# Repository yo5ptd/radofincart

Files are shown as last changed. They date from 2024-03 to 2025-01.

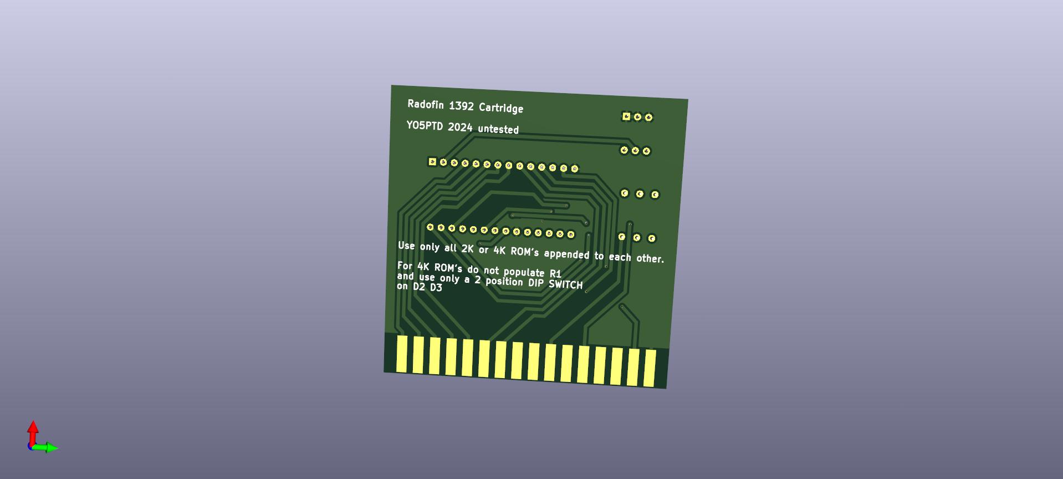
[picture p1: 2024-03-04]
radofin_back.jpg

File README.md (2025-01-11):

Radofin 1392 cartridge for 27128 ROM
If you just need a quick way to test a retro video computer

Supports 8 games in a single cartridge of size 2Kbytes or 4 games of 4Kbytes.

Use only 2K or 4K roms in a single ROM.

Use 27128 ROMS.

6 pin ic is actually a 3 pin DIP switch. For 4k ROM cartridge you can use 2 pin DIP switch.

11.01.2025:
added STL files for 3d printed case. You need to drill holes on the PCB.

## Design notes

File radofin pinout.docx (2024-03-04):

RADOFIN cartridge 2716/2732 reverse engineered YO5PTD 3/4/2023

Cartridge SIDE A | ROM | Cartridge SIDE A | ROM
1 A7 | 1 | 32 | 2 A6
2 A11 | 21 | 31 | 3 A5
3 A8 | 23 | 30 | 4 A4
4 A9 | 22 | 29 | 5 A3
5 A10 | 19 | 28 | 6 A2
6 /OE | 18 | 27 | 7 A1
7 | n/a | 26 | 8 A0
8 D7 | 17 | 25 | PAD
9 D6 | 16 | 24 | PAD
10 D5 | 15 | 23 | 24 VCC
11 D4 | 14 | 22 | n/a
12 D3 | 13 | 21 | 21 (gnd) / 2
13 D2 | 11 | 20 | n/a
14 D1 | 10 | 19 | n/a
15 D0 | 9 | 18 | 20 /G VPP
16 | n/a | 17 | 12 (gnd) /21

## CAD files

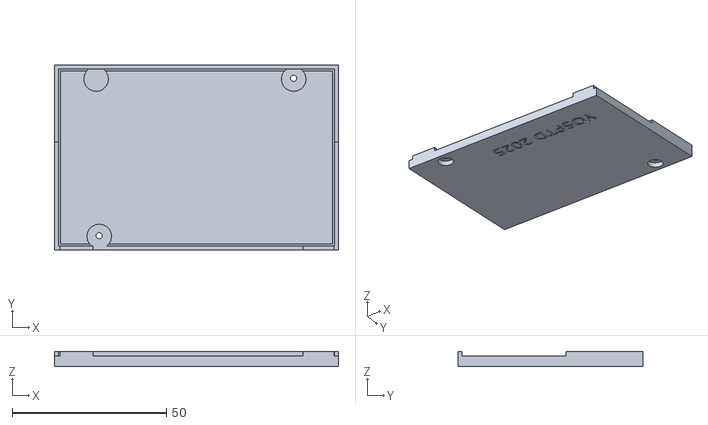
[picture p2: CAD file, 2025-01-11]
Radofin Cartridge Bottom.stl
92.0 x 60.0 x 5.00

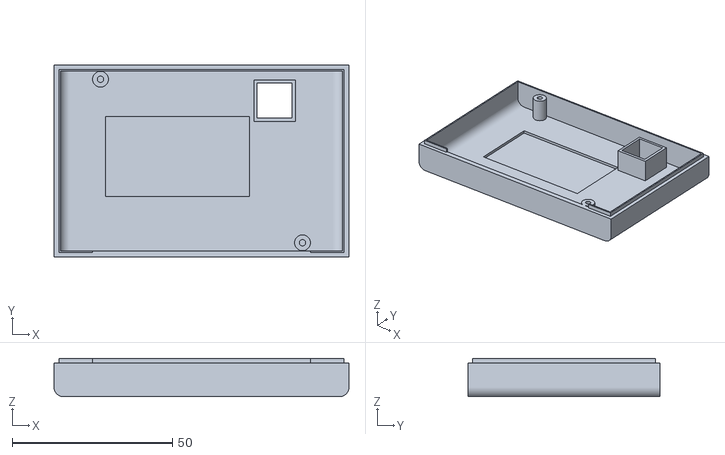
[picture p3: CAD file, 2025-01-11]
Radofin Cartridge Top.stl
92.0 x 60.0 x 12.0

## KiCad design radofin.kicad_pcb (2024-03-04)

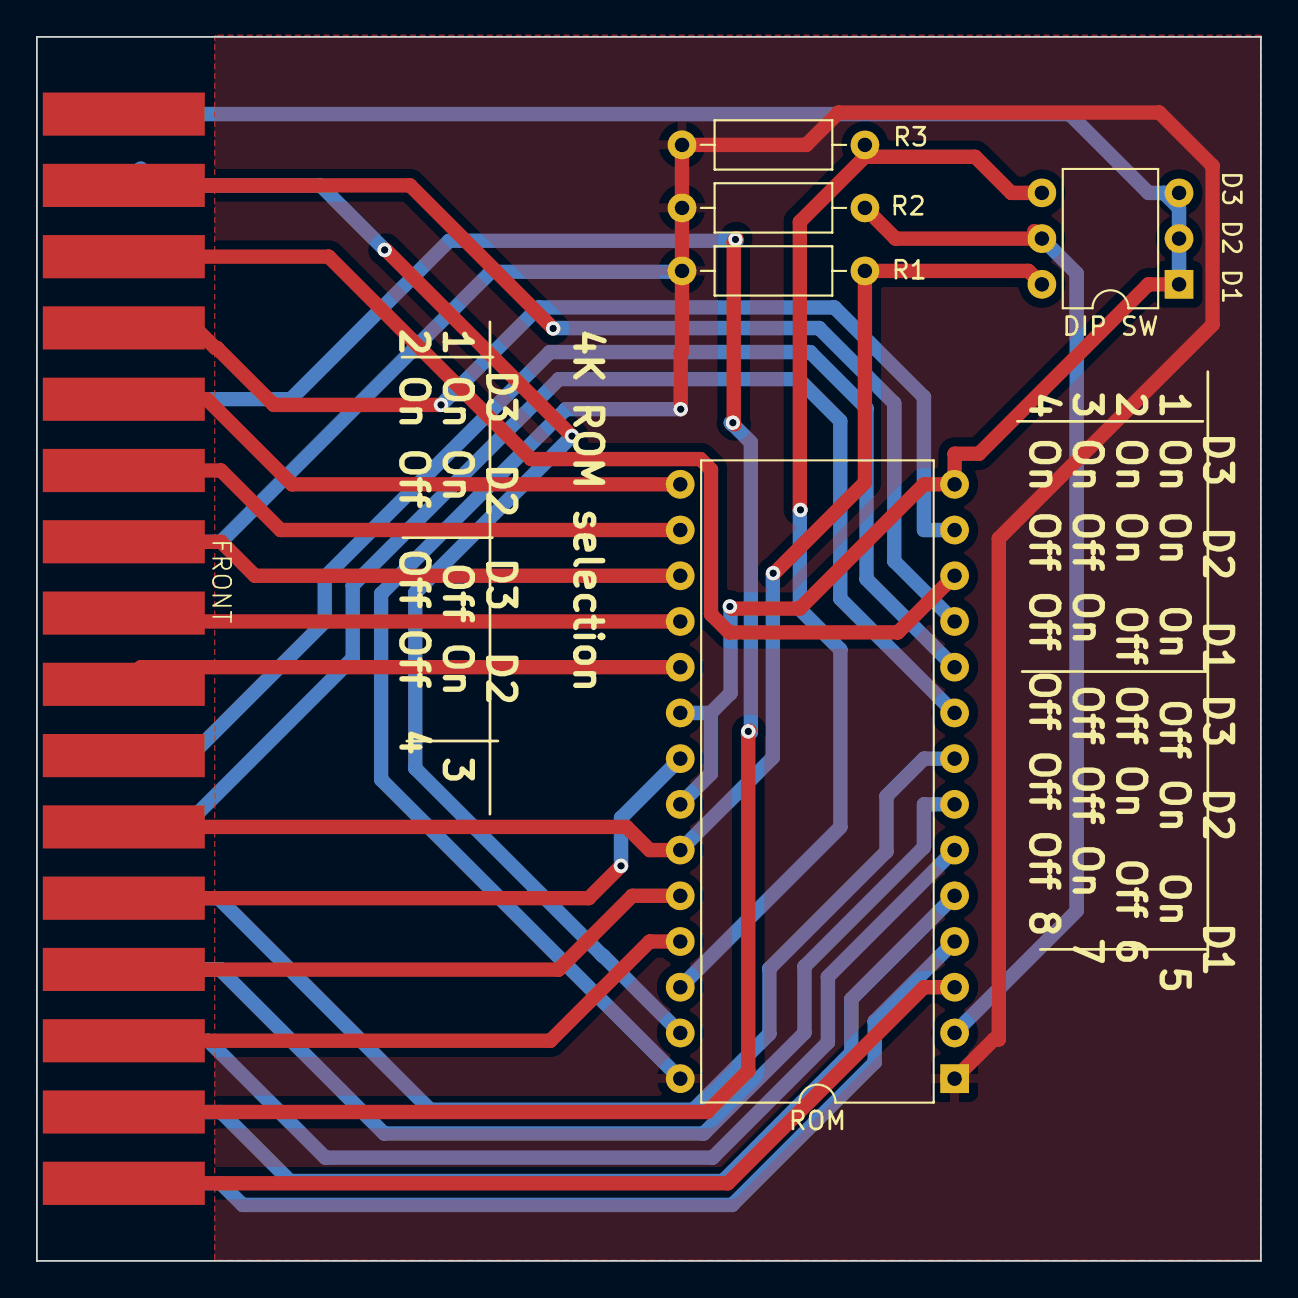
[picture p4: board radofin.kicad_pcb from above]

Board: 2 copper layers, 68.0 x 68.0 mm, 6 parts (0 on the bottom side), 26 nets.

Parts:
DIP SW: SW_DIP_x03; DIP-6_W7.62mm
FRONT: Conn_02x16_Counter_Clockwise; radofin
R1, R2, R3: 10k; R_Axial_DIN0207_L6.3mm_D2.5mm_P10.16mm_Horizontal
ROM: 27C128; DIP-28_W15.24mm

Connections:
/A0: FRONT.26, ROM.10 (A0)
/A1: FRONT.27, ROM.9 (A1)
/A2: FRONT.28, ROM.8 (A2)
/A3: FRONT.29, ROM.7 (A3)
/A4: FRONT.30, ROM.6 (A4)
/A5: FRONT.31, ROM.5 (A5)
/A6: FRONT.32, ROM.4 (A6)
/A7: FRONT.1, ROM.3 (A7)
/A8: FRONT.3, ROM.25 (A8)
/A9: FRONT.4, ROM.24 (A9)
/A10: FRONT.5, ROM.21 (A10)
/A11: DIP SW.6, FRONT.6, R1.1, ROM.23 (A11)
/A12: DIP SW.5, R2.1, ROM.2 (A12)
/A13: DIP SW.4, R3.1, ROM.26 (A13)
/D0: FRONT.15, ROM.11 (D0)
/D1: FRONT.14, ROM.12 (D1)
/D2: FRONT.13, ROM.13 (D2)
/D3: FRONT.12, ROM.15 (D3)
/D4: FRONT.11, ROM.16 (D4)
/D5: FRONT.10, ROM.17 (D5)
/D6: FRONT.9, ROM.18 (D6)
/D7: FRONT.8, ROM.19 (D7)
//PGM: FRONT.18, ROM.27 (~PGM)
GND: DIP SW.1, DIP SW.2, DIP SW.3, FRONT.17, ROM.14 (GND), ROM.20 (~CE), ROM.22 (~OE)
unnamed: FRONT.2, FRONT.21
VCC: FRONT.23, R1.2, R2.2, R3.2, ROM.1 (VPP), ROM.28 (VCC)

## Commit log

2024-03-04 Rewiring after an optical review
    [radofin-B_Cu.gbr, radofin-B_Mask.gbr, radofin-B_Paste.gbr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]
2025-01-11 3d printed case
    [Radofin Cartridge Bottom.stl, Radofin Cartridge Top.stl]
